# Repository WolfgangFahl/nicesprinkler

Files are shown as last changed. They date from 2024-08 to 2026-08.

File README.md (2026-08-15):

# nicesprinkler

Your lawn does not need a robot. It needs water in the right place.









Two stepper motors, a garden hose and a Raspberry Pi. One motor turns,
the other lifts, and the jet lands where the software says it should —
if the software knows the truth about the garden. Getting it to know
that is the interesting part.

[▶ watch it run](https://download.bitplan.com/lawnsprinkler/20240811_sprinkler.mp4) — two minutes of the real machine watering a real lawn.

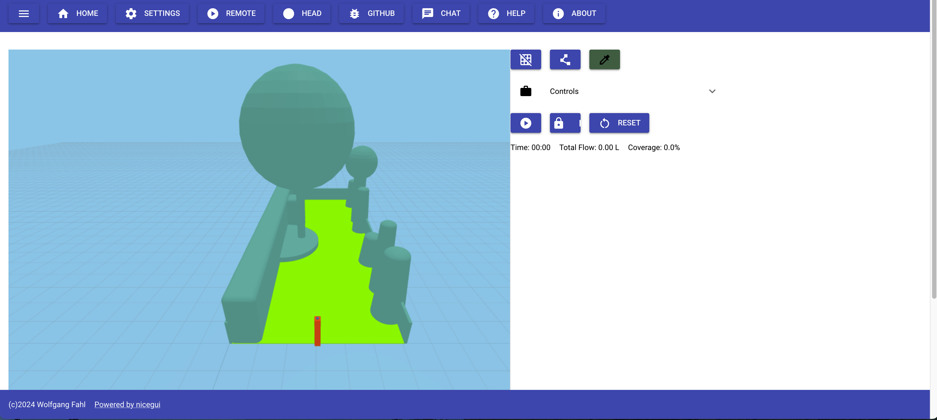
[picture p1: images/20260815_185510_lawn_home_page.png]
the garden in 3D


## What it does

- **Simulates** the throw over a 3D model of your garden before a drop falls
- **Aims** the head from the browser, or from a pattern
- **Watches** itself through the device camera while it works
- **Measures** its own flow with a bucket and a stopwatch, and remembers it

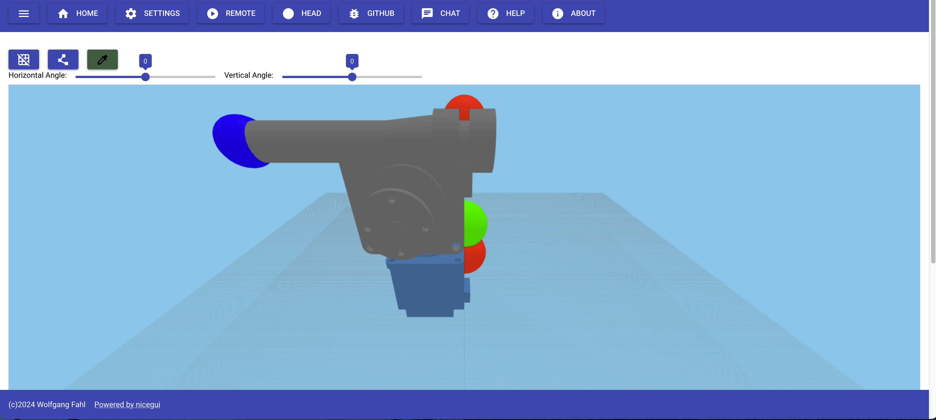
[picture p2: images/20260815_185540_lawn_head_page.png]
the sprinkler head


## Why the camera

A stepper says where it was told to go. Water pressure has opinions.
The hose bends, the head shifts under the jet, and the model drifts away
from the machine. So every frame the camera records is written with the
commanded angles beside it — pictures without angles teach nothing.

## Install

```bash
pip install nicesprinkler
```

## Run

```bash
sprinkler -s
```

Then open the address it prints. On a Raspberry Pi it drives the motors
through TB6600 drivers; anywhere else it runs the simulation with a mock
GPIO, so you can build the garden model on your laptop.

## Configure

Lawn size, head position, angle limits, hose specification and motor pins
live in one yaml. Start from `nicesprinkler_examples/example_config.yaml`.

## Documentation

- [API documentation](https://WolfgangFahl.github.io/nicesprinkler/)
- [Build instructions, parts list and wiring](https://wiki.bitplan.com/index.php/Lawn_Sprinkler)
- [Project page](https://wiki.bitplan.com/index.php/nicesprinkler)

## License

Apache 2.0

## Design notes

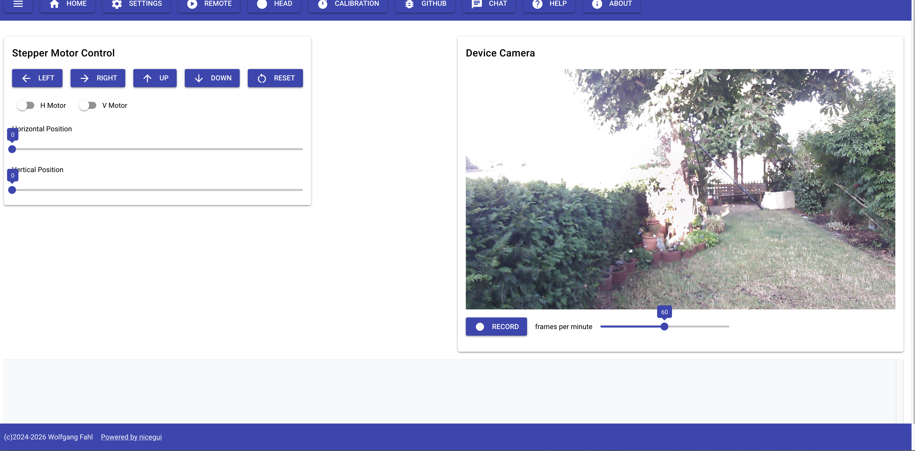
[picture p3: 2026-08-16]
images/20260816_090114_lawn_remote_camera.png

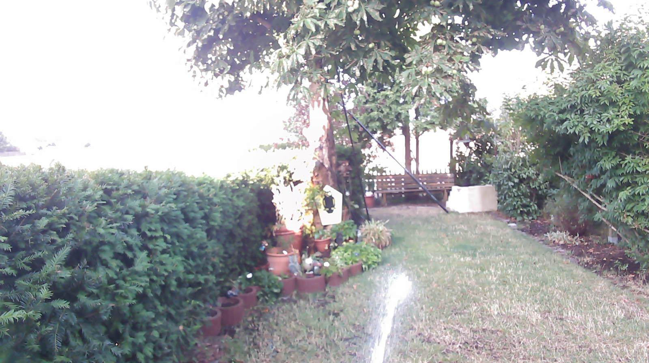
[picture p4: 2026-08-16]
images/20260816_085044_00207_devcam.jpg

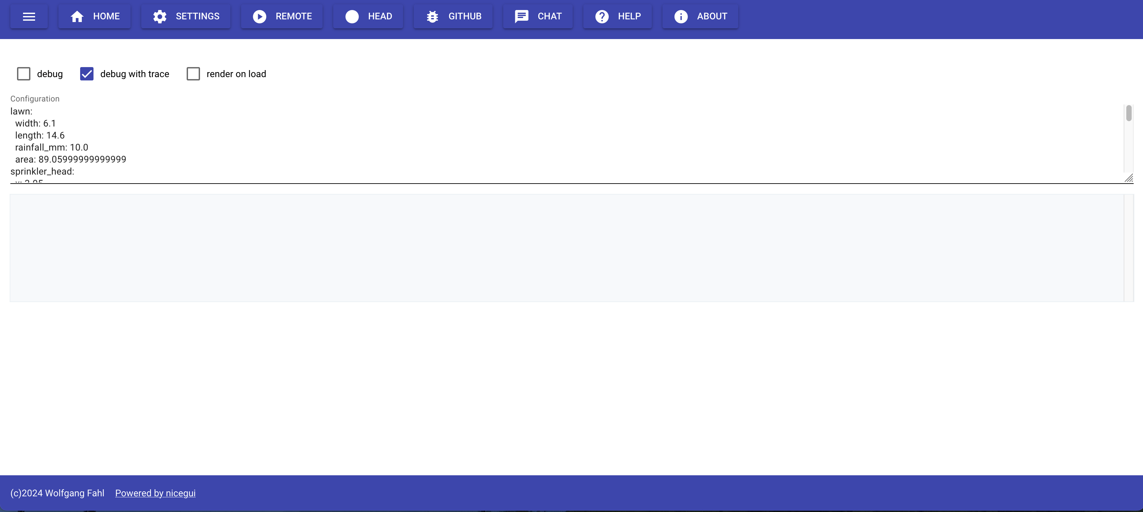
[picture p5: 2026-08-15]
images/20260815_185520_lawn_settings_page.png

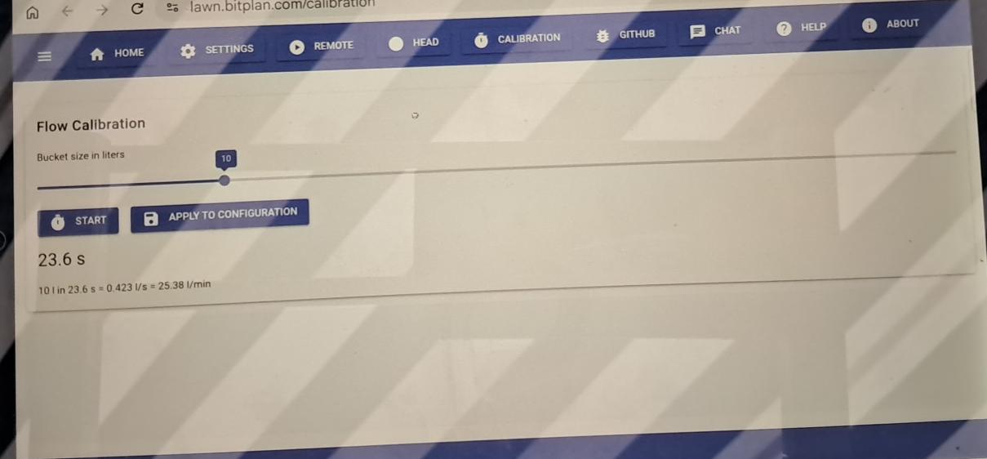
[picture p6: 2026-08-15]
images/20260815_193802_bucket_check.jpg

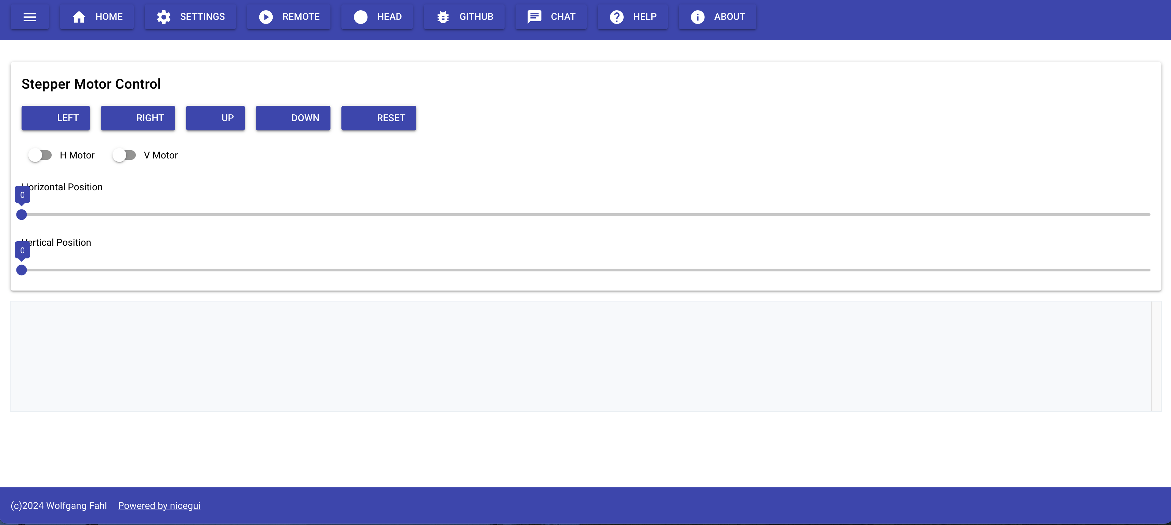
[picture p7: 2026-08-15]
images/20260815_185530_lawn_remote_page.png

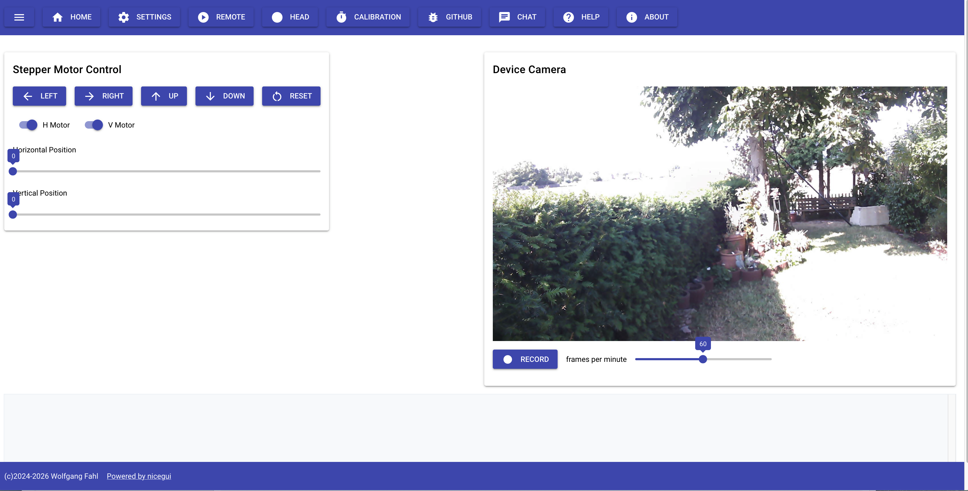
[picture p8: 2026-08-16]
images/20260816_103117_lawn_remote_switches.png

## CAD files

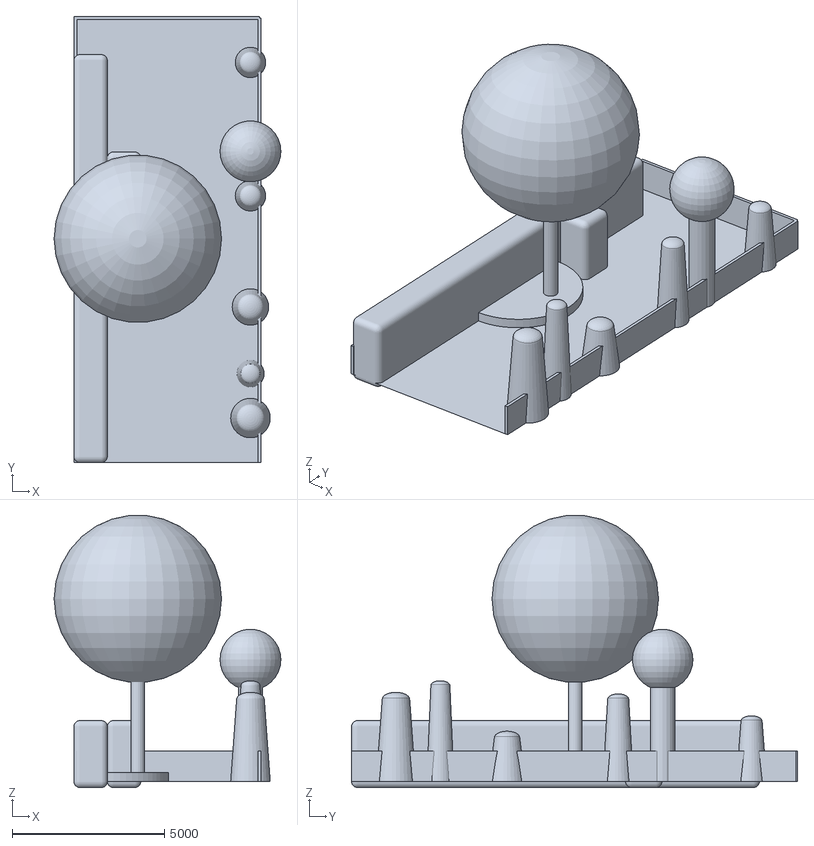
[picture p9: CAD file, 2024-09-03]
nicesprinkler_examples/example_garden.stl
7450.0 x 14650.0 x 8933.8

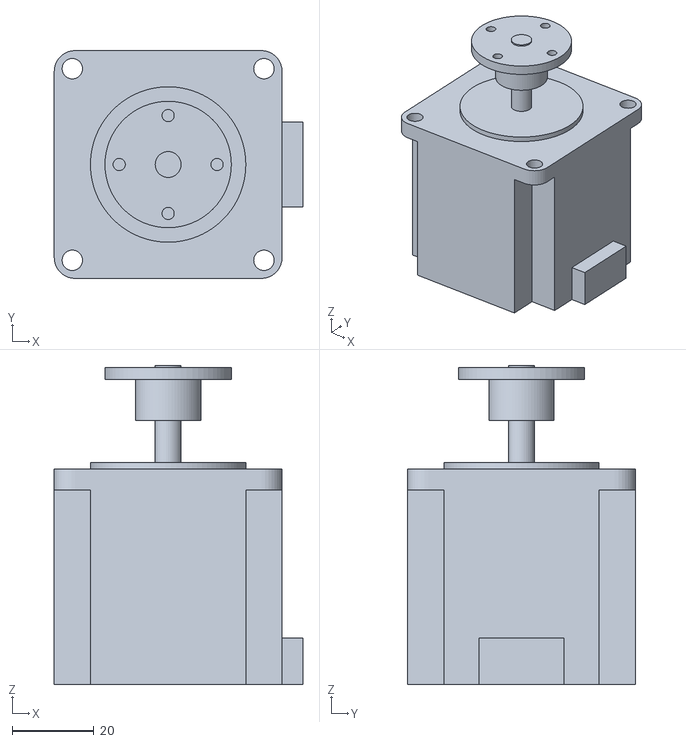
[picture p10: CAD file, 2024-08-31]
nicesprinkler_examples/nema23.stl
61.0 x 55.9 x 78.2

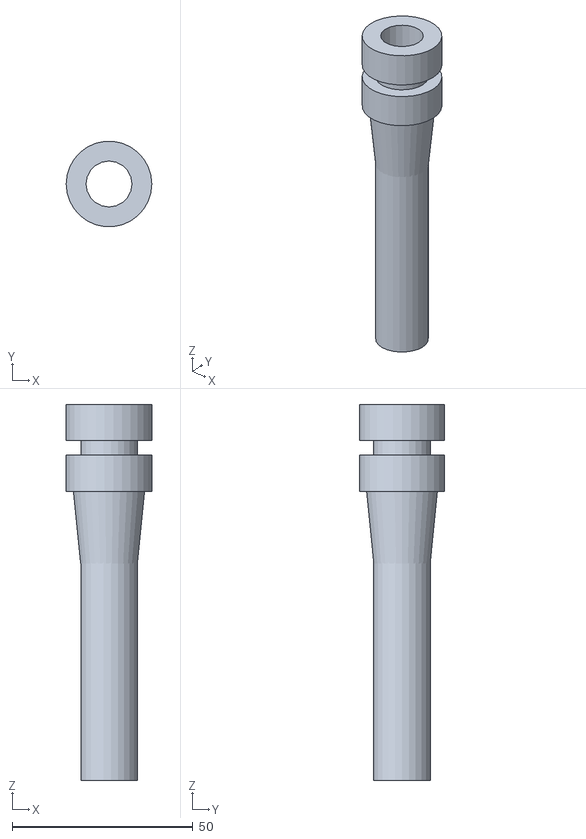
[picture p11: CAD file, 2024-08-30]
nicesprinkler_examples/hose.stl
23.7 x 23.6 x 104.0

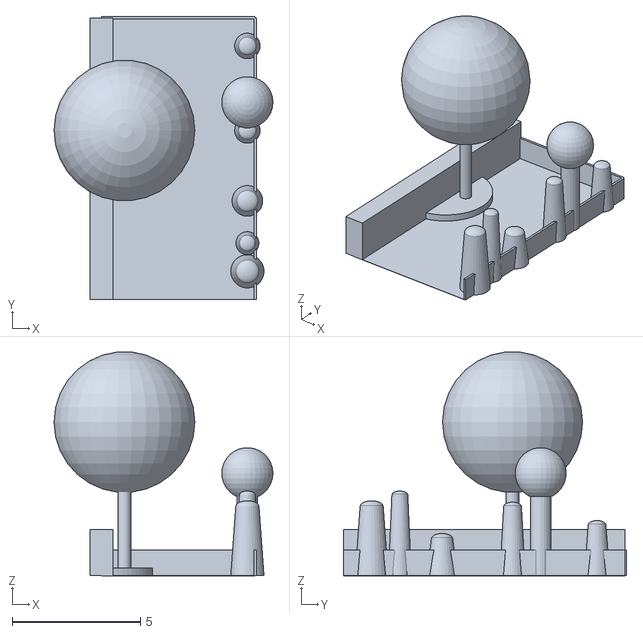
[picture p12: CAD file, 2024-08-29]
nicesprinkler_examples/example_garden1.stl
8.55 x 11.0 x 8.74

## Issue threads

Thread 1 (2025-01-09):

Base Configuration

WolfgangFahl, 2025-01-09:
## Purpose
Implement the configuration handling for the NiceSprinkler system to control the sprinkler head positioning and water flow parameters.

## User Story
As an administrator, I want to configure the physical parameters and motor controls of the sprinkler system so that it can operate within safe mechanical constraints and provide optimal lawn coverage.

## Requirements

### Must Have
- [ ] Configuration file in YAML format
- [ ] Configuration sections:
  - [ ] Lawn dimensions
    - [ ] Width
    - [ ] Length
  - [ ] Sprinkler head positioning
    - [ ] X coordinate
    - [ ] Y coordinate
    - [ ] Z height
  - [ ] Angular constraints
    - [ ] Horizontal angle range and step size
    - [ ] Vertical angle range and step size
  - [ ] Hose specifications
    - [ ] Diameter
    - [ ] Flow rate
    - [ ] Maximum spray distance
    - [ ] Maximum spray height
  - [ ] Motor configurations
    - [ ] Pin assignments
    - [ ] Steps per revolution
    - [ ] Angle limits
- [ ] Input validation for all parameters
- [ ] Safe loading of configuration
- [ ] Parameter range checking

## Example Configuration
```yaml
lawn:
  width: 6.1
  length: 14.6
sprinkler_head:
  x: 3.05
  y: 0.0
  z: 1.2
angles:
  horizontal:
    min: -85
    max: 85
    initial: 0
    step: 2
  vertical:
    min: -75
    max: 75
    initial: 0
    step: 2
hose:
   diameter: 12.7 # half inch
   flow_rate: 20 # l/min
   max_distance: 13.6
   max_height: 5.7
motors:
  horizontal:
    ena_pin: 37
    dir_pin: 35
    pul_pin: 33
    steps_per_revolution: 200
    min_angle: -90
    max_angle: 90
  vertical:
    ena_pin: 31
    dir_pin: 29
    pul_pin: 23
    steps_per_revolution: 200
    min_angle: 0
    max_angle: 60

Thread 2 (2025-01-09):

STL based lawn configuration

WolfgangFahl, 2025-01-09:
## Purpose
Add support for STL files to define the lawn shape, obstacles, and sprinkler positions to enable more accurate coverage planning and collision avoidance.

## User Story
As an administrator, I want to use 3D models (STL files) to define my lawn layout including obstacles like trees, so the sprinkler can optimize its coverage pattern and avoid spraying non-lawn areas.

## Requirements

### Must Have
- [ ] STL file support for:
  - [ ] Lawn boundary definition
  - [ ] Ground level/terrain mapping
  - [ ] Obstacle positions (trees, bushes, furniture)
  - [ ] Sprinkler mounting position
- [ ] Validation of STL files:
  - [ ] Verify scale matches YAML configuration
  - [ ] Ensure sprinkler position is valid
  - [ ] Check for mesh intersections
- [ ] Integration with existing YAML config:
  - [ ] Reference to STL files
  - [ ] Override options for sprinkler position
  - [ ] Scale factors if needed

### Example Configuration
```yaml
lawn:
  model: "lawn_boundary.stl"
  scale: 1.0  # 1 unit = 1 meter
prinkler_head:
  model: "sprinkler_mount.stl"  # Optional, for collision checking
  position:
    inherit: true  # Use position from STL
    override:      # Optional override
      x: 3.05
      y: 0.0
      z: 1.2

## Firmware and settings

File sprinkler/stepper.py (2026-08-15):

"""
Created on 13.08.2024

@author: wf
"""

"""
stepper.py

Control two stepper motors connected to a Raspberry Pi through a TB6600 driver to sprinkle a lawn.

Author: Wolfgang, ChatGPT, Claude AI
Date: 2024-07 to 2024-08
"""

import argparse
import time
from typing import Dict

try:
    import RPi.GPIO as GPIO
except (ImportError, RuntimeError):
    # Create a dummy GPIO module if the import fails (for non-Raspberry Pi environments)
    print(
        "RPi.GPIO module not found. Using a mock version for non-Raspberry Pi environment."
    )

    class GPIO:
        BOARD = None
        OUT = None
        HIGH = 1
        LOW = 0
        # pin states of the mock, so that reading back works off the device
        states = {}

        @staticmethod
        def setmode(mode):
            pass

        @staticmethod
        def setup(pin, mode):
            GPIO.states.setdefault(pin, GPIO.LOW)

        @staticmethod
        def output(pin, state):
            GPIO.states[pin] = state

        @staticmethod
        def input(pin):
            return GPIO.states.get(pin, GPIO.LOW)

        @staticmethod
        def cleanup():
            GPIO.states.clear()


class StepperMotor:
    def __init__(
        self,
        name: str,
        ena_pin: int,
        dir_pin: int,
        pul_pin: int,
        steps_per_revolution: int = 200,
        direction: int = 1,
    ):
        self.name = name
        self.ena_pin = ena_pin
        self.dir_pin = dir_pin
        self.pul_pin = pul_pin
        self.steps_per_revolution = steps_per_revolution
        self.direction = direction
        self.setup_gpio()

    def setup_gpio(self):
        GPIO.setup(self.ena_pin, GPIO.OUT)
        GPIO.setup(self.dir_pin, GPIO.OUT)
        GPIO.setup(self.pul_pin, GPIO.OUT)
        GPIO.output(self.ena_pin, GPIO.HIGH)  # Start with motor disabled

    def enable(self):
        GPIO.output(self.ena_pin, GPIO.LOW)

    def disable(self):
        GPIO.output(self.ena_pin, GPIO.HIGH)

    @property
    def enabled(self) -> bool:
        """The real pin state - low is enabled - rather than a remembered one."""
        return GPIO.input(self.ena_pin) == GPIO.LOW

    def set_direction(self, clockwise: bool):
        """Set the direction pin, with the configured sign of this axis."""
        if self.direction < 0:
            clockwise = not clockwise
        GPIO.output(self.dir_pin, GPIO.HIGH if clockwise else GPIO.LOW)

    def step(self, steps: int, delay: float):
        for _ in range(abs(steps)):
            GPIO.output(self.pul_pin, GPIO.HIGH)
            time.sleep(delay)
            GPIO.output(self.pul_pin, GPIO.LOW)
            time.sleep(delay)


class Move:
    """
    The motors of the machine.

    One instance per process: the enable state lives in the hardware and a
    second instance would reset it, so views share this one.
    """

    def __init__(self, config=None):
        """
        Args:
            config: SprinklerConfig whose motors section carries the pins,
                the steps per revolution and the direction sign. Without it
                the wiring defaults of the documented build are used.
        """
        GPIO.setmode(GPIO.BOARD)
        self.motors: Dict[int, StepperMotor] = {}
        motors = getattr(config, "motors", None) if config else None
        if motors:
            for motor_id, name in ((1, "horizontal"), (2, "vertical")):
                mc = getattr(motors, name)
                self.motors[motor_id] = StepperMotor(
                    name.capitalize(),
                    mc.ena_pin,
                    mc.dir_pin,
                    mc.pul_pin,
                    mc.steps_per_revolution,
                    getattr(mc, "direction", 1),
                )
        else:
            self.motors = {
                1: StepperMotor("Motor1", 37, 35, 33),
                2: StepperMotor("Motor2", 31, 29, 23),
            }

    def enable_motor(self, motor_id: int):
        motor = self.motors.get(motor_id)
        if motor:
            motor.enable()
        else:
            print(f"Motor {motor_id} not found")

    def disable_motor(self, motor_id: int):
        motor = self.motors.get(motor_id)
        if motor:
            motor.disable()
        else:
            print(f"Motor {motor_id} not found")

    def move_motor(
        self, motor_id: int, angle: float, speed_rpm: float, keep_enabled: bool = False
    ):
        motor = self.motors.get(motor_id)
        if not motor:
            print(f"Motor {motor_id} not found")
            return
        steps = int(abs(angle) / 360 * motor.steps_per_revolution)
        delay = 30 / (speed_rpm * motor.steps_per_revolution)
        motor.enable()
        motor.set_direction(angle >= 0)
        motor.step(steps, delay)
        if not keep_enabled:
            motor.disable()

    def perform_pattern(
        self,
        horizontal_angle: float,
        horizontal_steps: int,
        vertical_angle: float,
        rpm: float,
    ):
        # Enable both motors before starting the pattern
        self.enable_motor(1)
        self.enable_motor(2)

        for _ in range(horizontal_steps):
            self.move_motor(1, horizontal_angle, rpm, keep_enabled=True)
            self.move_motor(2, vertical_angle, rpm, keep_enabled=True)
            self.move_motor(2, -vertical_angle, rpm, keep_enabled=True)

        # Reset horizontal position
        self.move_motor(1, -horizontal_angle * horizontal_steps, rpm, keep_enabled=True)

        # Disable both motors after completing the pattern
        self.disable_motor(1)
        self.disable_motor(2)

    def perform_pattern_by_args(self, pattern_args):
        # Default values
        params = {"steps": 80, "hangle": 160, "vangle": 120, "rpm": 10}

        # Parse provided arguments
        for arg in pattern_args:
            key, value = arg.split("=")
            if key in params:
                params[key] = float(value)

        # Execute the pattern
        self.perform_pattern(
            horizontal_angle=params["hangle"] / params["steps"],
            horizontal_steps=int(params["steps"]),
            vertical_angle=params["vangle"],
            rpm=params["rpm"],
        )

    def cleanup(self):
        for motor in self.motors.values():
            motor.disable()
        GPIO.cleanup()
        time.sleep(0.1)


# Modify main function to use the new approach
def main():
    parser = argparse.ArgumentParser(description="Control stepper motors")
    parser.add_argument(
        "-m", "--motor", type=int, default=1, help="Motor ID (default: 1)"
    )
    parser.add_argument(
        "-a",
        "--angle",
        type=float,
        default=15,
        help="Angle to rotate (default: 15, positive for CW, negative for CCW)",
    )
    parser.add_argument(
        "-r", "--rpm", type=float, default=20, help="Speed in RPM (default: 20)"
    )
    parser.add_argument(
        "-k",
        "--keep-enabled",
        action="store_true",
        help="Keep motor enabled after movement",
    )
    parser.add_argument(
        "-p",
        "--pattern",
        nargs="*",
        metavar="KEY=VALUE",
        help="Perform pattern: [steps=N] [hangle=DEG] [vangle=DEG] [rpm=RPM] default: steps=20,hangle=160,vangle=90,rpm=10",
    )

    args = parser.parse_args()
    move_controller = Move()

    if args.pattern is not None:
        # For pattern, we'll handle enabling/disabling within the perform_pattern method
        move_controller.perform_pattern_by_args(args.pattern)
    else:
        # For single motor movement
        move_controller.move_motor(args.motor, args.angle, args.rpm, args.keep_enabled)

    move_controller.cleanup()


if __name__ == "__main__":
    main()

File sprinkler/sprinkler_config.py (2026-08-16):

"""
Created on 2024-09-03

@author: wf
"""

import math
from dataclasses import field
from typing import List

from basemkit.yamlable import lod_storable
from tabulate import tabulate


@lod_storable
class Point3D:
    x: float
    y: float
    z: float

    def __add__(self, other):
        return Point3D(self.x + other.x, self.y + other.y, self.z + other.z)

    def __mul__(self, scalar):
        return Point3D(self.x * scalar, self.y * scalar, self.z * scalar)

    def __rmul__(self, scalar):
        return self.__mul__(scalar)

    def to_tuple(self):
        return (self.x, self.y, self.z)


@lod_storable
class Lawn:
    """
    Lawn dimensions (meter)
    """

    width: float
    length: float
    rainfall_mm: float = (
        10  # default rainfall equivalent needed to properly wet the lawn
    )

    area: float = field(init=False)  # This field is not expected as input

    def __post_init__(self):
        # Calculate the area after the object is initialized
        self.area = self.width * self.length

    def rain_mm_to_l(self, rainfall_mm: float = None) -> float:
        """
        Calculate the volume of rainwater in liters given the rainfall in millimeters.
        """
        # 1 mm of rain on 1 square meter equals 1 liter of water
        if rainfall_mm is None:
            rainfall_mm = self.rainfall_mm
        return self.area * rainfall_mm


class SprinklerHead(Point3D):
    """
    Sprinkler head position relative to lawn (meter)
    """


@lod_storable
class AngleRange:
    """
    Defines a range of angles with a minimum, maximum, and step size and
    precaluclated angles
    """

    min: float
    max: float
    initial: float
    step: float
    angles: List[float] = field(init=False)

    def __post_init__(self):
        # Generate the list of angles based on the provided range
        self.angles = self.generate_angles()

    def generate_angles(self) -> List[float]:
        """
        Generate a list of angles based on the AngleRange specification.
        """
        angles = []
        current = self.min
        while current <= self.max:
            angles.append(current)
            current += self.step
        return angles


@lod_storable
class Angles:
    """
    Angle configuration for the sprinkler
    """

    horizontal: AngleRange
    vertical: AngleRange


@lod_storable
class Hose:
    """
    Hose specifications with calibration capabilities.
    """

    diameter: float = 25.4 / 2  # half inch hose, diameter in mm
    flow_rate: float = 11.5  # flow rate in l/min
    max_distance: float = 7.4  # Maximum horizontal distance reached (meters)
    max_height: float = 3.35  # Maximum vertical height reached (meters)

    pressure: float = field(init=False)  # Pressure in bar, will be calculated
    velocity: float = field(init=False)  # Velocity in m/s, will be calculated
    nozzle_area: float = field(
        init=False
    )  # Nozzle area in square mm, will be calculated
    nozzle_diameter: float = field(
        init=False
    )  # Nozzle diameter in mm, will be calculated

    def __post_init__(self):
        self.recalculate()

    def calibrate(self, max_distance: float, max_height: float, flow_rate: float):
        """
        Calibrate the hose based on measured values.
        """
        self.max_distance = max_distance
        self.max_height = max_height
        self.flow_rate = flow_rate
        self.recalculate()

    def recalculate(self):
        # Use max_height to calculate initial velocity
        self.velocity = math.sqrt(2 * 9.8 * self.max_height)

        # Calculate nozzle area in square mm
        self.nozzle_area = (self.flow_rate / 60) / (self.velocity * 1000) * 1e6
        self.nozzle_diameter = 2 * math.sqrt(
            self.nozzle_area / math.pi
        )  # Diameter in mm

        # Calculate pressure in bar
        self.pressure = self.max_height * 9.8 / 100

    def spray_distance(self, angle: float) -> float:
        """
        Calculate the spray distance for the given angle of spray.
        """
        t = 2 * self.velocity * math.sin(math.radians(angle)) / 9.8
        spray_distance = self.velocity * math.cos(math.radians(angle)) * t
        return spray_distance

    def specs(self, tablefmt: str = "pipe") -> str:
        """
        Return the hose specifications as a formatted string using tabulate.
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

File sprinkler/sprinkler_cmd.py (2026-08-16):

"""
Created on 2024-08-13

@author: wf
"""

import sys
from argparse import ArgumentParser

from ngwidgets.cmd import WebserverCmd

from sprinkler.webserver import NiceSprinklerWebServer


class NiceSprinklerCmd(WebserverCmd):
    """
    command line handling for nicesprinkler
    """

    def __init__(self):
        """
        constructor
        """
        config = NiceSprinklerWebServer.get_config()
        WebserverCmd.__init__(self, config, NiceSprinklerWebServer, DEBUG)

    def getArgParser(self, description: str, version_msg) -> ArgumentParser:
        """
        override the default argparser call
        """
        parser = super().getArgParser(description, version_msg)
        parser.add_argument(
            "--config",
            default="config.yaml",
            help="path to the sprinkler configuration file, relative to the installation directory [default: %(default)s]",
        )
        parser.add_argument(
            "--stl",
            default="garden.stl",
            help="path to the garden model, relative to the installation directory [default: %(default)s]",
        )
        return parser


def main(argv: list = None):
    """
    main call
    """
    cmd = NiceSprinklerCmd()
    exit_code = cmd.cmd_main(argv)
    return exit_code


DEBUG = 0
if __name__ == "__main__":
    if DEBUG:
        sys.argv.append("-d")
    sys.exit(main())

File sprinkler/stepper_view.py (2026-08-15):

from dataclasses import dataclass

from nicegui import ui

from sprinkler.sprinkler_core import SprinklerSystem
from sprinkler.stepper import Move, StepperMotor


@dataclass
class MotorView:
    """
    One motor on the remote control page.

    The enable state is not remembered here - it is read from the pin, so
    a page reload or a reconnect cannot make the page and the machine
    disagree.
    """

    name: str
    id: int
    motor: StepperMotor = None
    position: float = 0
    slider: ui.slider = None

    @property
    def enabled(self) -> bool:
        return self.motor.enabled if self.motor else False

    def enable(self, move_controller: Move):
        move_controller.enable_motor(self.id)

    def disable(self, move_controller: Move):
        move_controller.disable_motor(self.id)

    def move(self, move_controller: Move, angle: float, rpm: float):
        if self.enabled:
            move_controller.move_motor(self.id, angle, rpm, keep_enabled=True)
            self.position += angle
            if self.slider:
                self.slider.set_value(self.position)

    def update_position(self, move_controller: Move, new_position: float, rpm: float):
        if self.enabled:
            delta = new_position - self.position
            self.move(move_controller, delta, rpm)


class StepperView:
    """
    Remote control page for the two stepper motors.
    """

    def __init__(self, solution, sprinkler_system: SprinklerSystem, step_size: int = 2):
        self.solution = solution
        self.sprinkler_system = sprinkler_system
        # one controller per process - see the enable state note in Move
        self.move_controller = getattr(solution.webserver, "move_controller", None)
        if self.move_controller is None:
            self.move_controller = Move(sprinkler_system.config)
            solution.webserver.move_controller = self.move_controller
        self.step_size = step_size
        self.motor_h = MotorView("Horizontal", 1, self.move_controller.motors.get(1))
        self.motor_v = MotorView("Vertical", 2, self.move_controller.motors.get(2))

    def setup_ui(self):
        with ui.card():
            ui.label("Stepper Motor Control").classes("text-h6")

            with ui.row():
                ui.button(
                    "Left",
                    icon="arrow_back",
                    on_click=lambda: self.motor_h.move(
                        self.move_controller, -self.step_size, self.step_size
                    ),
                )
                ui.button(
                    "Right",
                    icon="arrow_forward",
                    on_click=lambda: self.motor_h.move(
                        self.move_controller, self.step_size, self.step_size
                    ),
                )
                ui.button(
                    "Up",
                    icon="arrow_upward",
                    on_click=lambda: self.motor_v.move(
                        self.move_controller, -self.step_size, self.step_size
                    ),
                )
                ui.button(
                    "Down",
                    icon="arrow_downward",
                    on_click=lambda: self.motor_v.move(
                        self.move_controller, self.step_size, self.step_size
                    ),
                )
                ui.button("Reset", icon="restart_alt", on_click=self.reset_origin)

            with ui.row():
                # the value comes from the pin, not from memory
                ui.switch(
                    "H Motor",
                    value=self.motor_h.enabled,
                    on_change=lambda e: self.toggle_motor(self.motor_h, e.value),
                )
                ui.switch(
                    "V Motor",
                    value=self.motor_v.enabled,
                    on_change=lambda e: self.toggle_motor(self.motor_v, e.value),
                )

            ui.label("Horizontal Position")
            self.motor_h.slider = ui.slider(
                min=0,
                max=360,
                value=self.motor_h.position,
                on_change=lambda e: self.motor_h.update_position(
                    self.move_controller, e.value, 10
                ),
            ).props("label-always")

            ui.label("Vertical Position")
            self.motor_v.slider = ui.slider(
                min=0,
                max=360,
                value=self.motor_v.position,
                on_change=lambda e: self.motor_v.update_position(
                    self.move_controller, e.value, 10
                ),
            ).props("label-always")

    def toggle_motor(self, motor: MotorView, enabled: bool):
        if enabled:
            motor.enable(self.move_controller)
        else:
            motor.disable(self.move_controller)

    def reset_origin(self):
        for motor in [self.motor_h, self.motor_v]:
            if motor.enabled:
                motor.move(self.move_controller, -motor.position, 10)
            motor.position = 0
            motor.slider.set_value(0)

    def cleanup(self):
        self.move_controller.cleanup()

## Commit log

2024-08-22 release commit
    [example_garden.stl]
2024-08-29 adds controls
    [example_garden.stl, example_garden1.stl]
2024-08-30 adds hose and nema23 stl files and vstart script
    [hose.stl, nema23.stl]
2024-08-31 improves nema with 4 hole flange and add sprinkler head
    [nema23.stl]
2024-09-01 fixes tests
    [example_garden.stl]
2024-09-03 improves SprinklerConfig
    [example_garden.stl]
2024-09-05 refactors stl code to separate module
2026-08-15 fixes -v/--verbose conflict with ngwidgets base class
    [sprinkler_cmd.py]
2026-08-15 adds head geometry defect capture at h=5 v=-31
2026-08-15 adds flow calibration page - closes #3
2026-08-15 adds calibration page capture
2026-08-15 adds calibration traceback capture
2026-08-15 fixes value change handlers for nicegui 2 and adds the device camera to the remote view - see #10 #9
    [calibration.py, camera.py, stepper_view.py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]
2026-08-15 registers the camera frame route at server start
2026-08-15 adds remote view with camera capture
2026-08-15 serves the camera as an mjpeg stream at full width - flicker and size, see #9
2026-08-15 adds the bucket check capture
2026-08-15 adds the streamed remote camera capture
2026-08-15 reads the camera with linuxpy instead of ffmpeg - closes nothing, see #13
2026-08-15 adds the record button with sidecars carrying the commanded angles and fixes the button icons - closes #14 #15
    [camera.py, stepper_view.py, webserver.py]
2026-08-15 starts the camera when a frame is requested without an open page
2026-08-16 adds the remote page capture on 0.0.3 with the linuxpy camera - see #9
2026-08-16 adds four frames of the labelled left to right sweep of session 20260816_084715 - see #13
2026-08-16 adds token protected commanding routes for the camera and the two motors - closes #22
2026-08-16 serves the configured camera rotation as an exif orientation and steps it with a debug only button - closes #28
